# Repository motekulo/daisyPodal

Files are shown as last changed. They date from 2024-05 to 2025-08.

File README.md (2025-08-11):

# Crouds

A guitar pedal that will run patches prototyped on a Daisy Pod. I've started with making it through hole and accessible to build.

[Here's a demo](https://www.youtube.com/watch?v=Z1YsjiImZnQ) of some of the early effects and overall idea.

## Thanks

- For hardware thanks to work on the Dasiy Petal, the Terrarium and the work of  [Keith Shepherd](https://github.com/bkshepherd) 
- Timothy Schoen and other developers (Alex Mitchell, for example) for Plugdata
- Wasted Audio for the [Heavy hvcc compiler](https://wasted-audio.github.io/hvcc/)
- Graham Wakefield and Gregory Taylor for [Generating Sound and Organizing Time](https://cycling74.com/books/go)

## Things to do - v0.3 to 0.4

- J1-8 labels can go on back of board as well
- fix encoder pins (currently the wrong way around)
- fix schematic connection between pins 1 and 2 of TL074
- increase width of board, and bevel corners to fit in enclosure

## Videos

[Version 0.3 with a delay/ looper patch](https://youtu.be/q5X9XX3Vkqw)

[Version 0.3 with a distortion patch](https://youtu.be/5CY0gC0ThXo)

## Roadmap
SMD version as well as through hole.

## About me
I'm a musician/ lecturer - https://researchers.mq.edu.au/en/persons/denis-crowdy, https://codemusic.studio

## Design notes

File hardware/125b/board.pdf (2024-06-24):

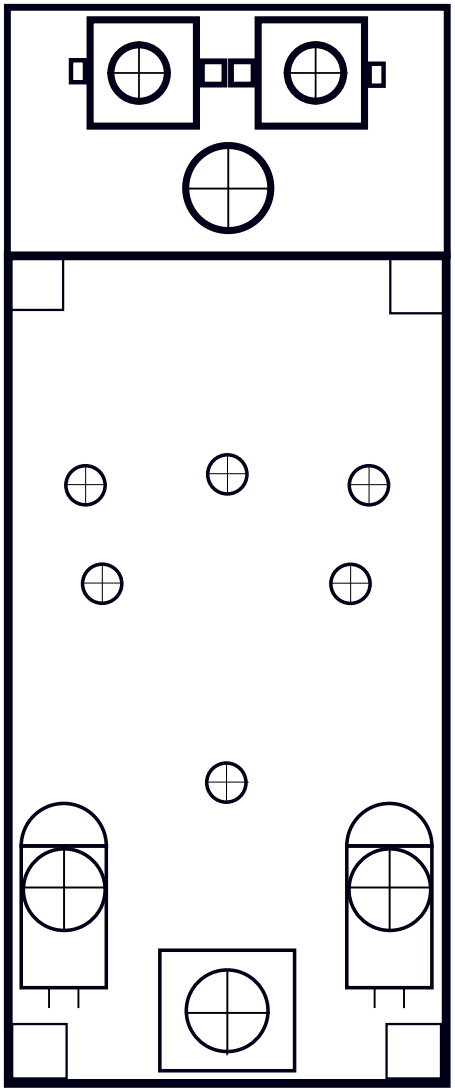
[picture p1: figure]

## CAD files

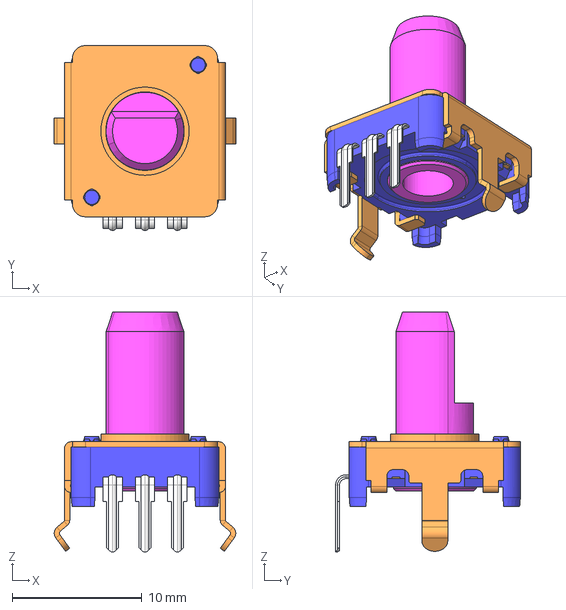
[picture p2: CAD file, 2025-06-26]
hardware/3dmodels/ec12e24204a2.stp
14.0 x 14.2 x 18.5 mm

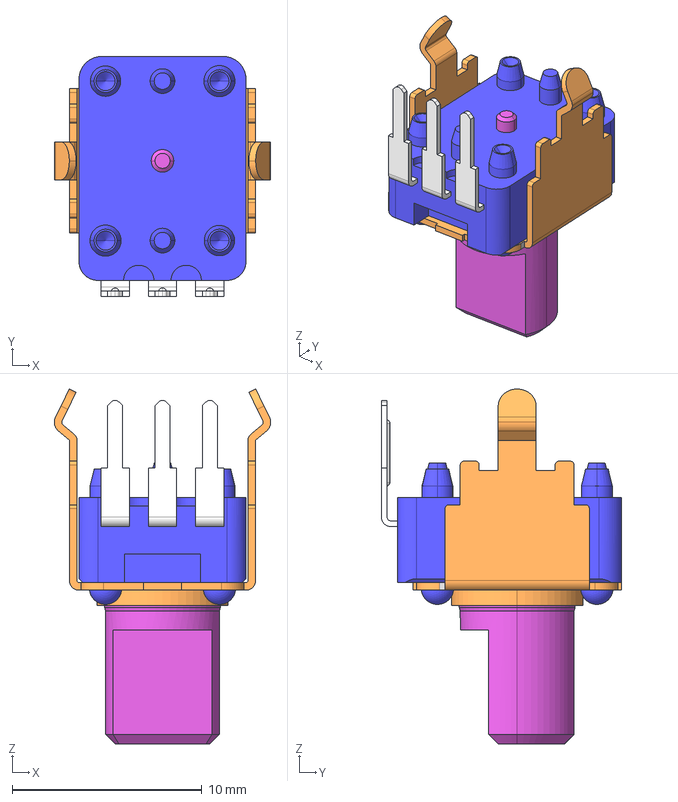
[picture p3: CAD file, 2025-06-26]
hardware/3dmodels/rk09k1130a6s.stp
11.4 x 12.7 x 18.7 mm

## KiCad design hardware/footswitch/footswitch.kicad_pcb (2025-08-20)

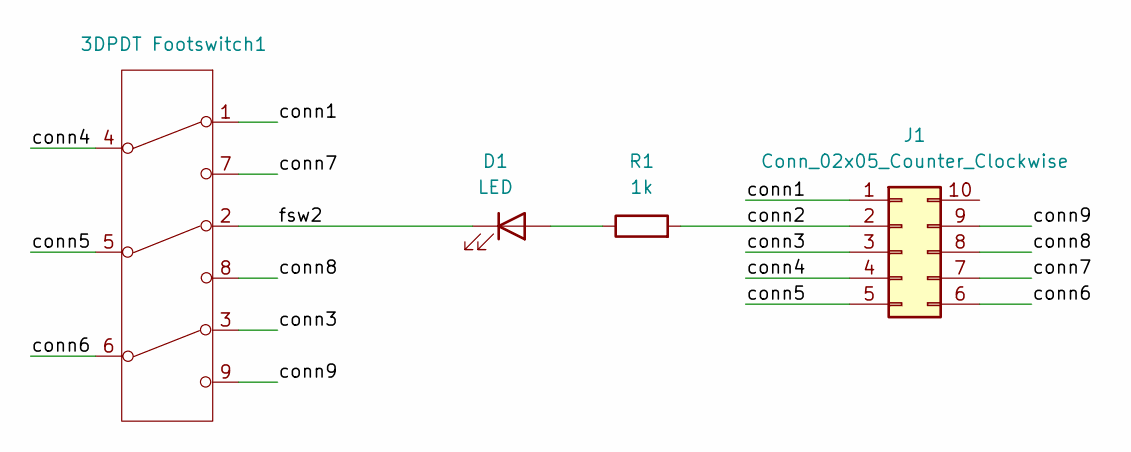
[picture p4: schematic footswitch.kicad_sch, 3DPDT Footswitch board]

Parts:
3DPDT Footswitch1: Switches_Stomp_Switch_3PDT
D1: LED; LED_D1.8mm_W3.3mm_H2.4mm
J1: Conn_02x05_Counter_Clockwise; IDC-Header_2x05_P2.54mm_Vertical
R1: 1k; R_Axial_DIN0207_L6.3mm_D2.5mm_P10.16mm_Horizontal

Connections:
/conn1: 3DPDT Footswitch1.1 (A), J1.1
/conn2: J1.2, R1.2
/conn3: 3DPDT Footswitch1.3 (C), J1.3
/conn4: 3DPDT Footswitch1.4 (D), J1.4
/conn5: 3DPDT Footswitch1.5 (E), J1.5
/conn6: 3DPDT Footswitch1.6 (F), J1.6
/conn7: 3DPDT Footswitch1.7 (G), J1.7
/conn8: 3DPDT Footswitch1.8 (G), J1.8
/conn9: 3DPDT Footswitch1.9 (G), J1.9
/fsw2: 3DPDT Footswitch1.2 (B), D1.1 (K)
unnamed: D1.2 (A), R1.1

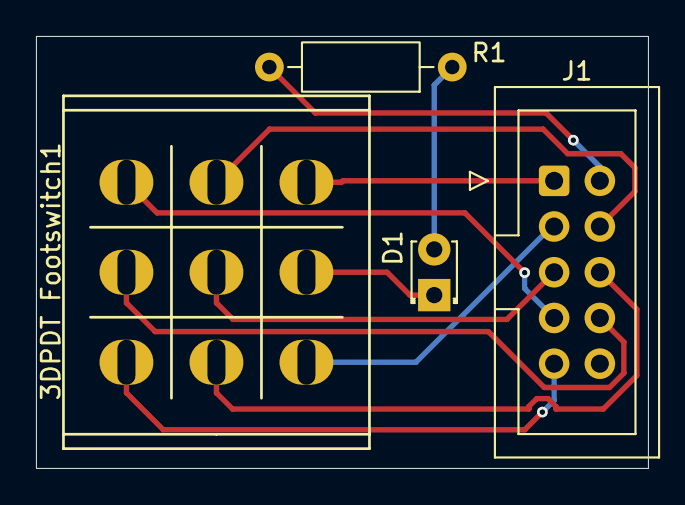
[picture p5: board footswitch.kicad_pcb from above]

Board: 2 copper layers, 34.0 x 24.0 mm, 4 parts (0 on the bottom side), 11 nets.

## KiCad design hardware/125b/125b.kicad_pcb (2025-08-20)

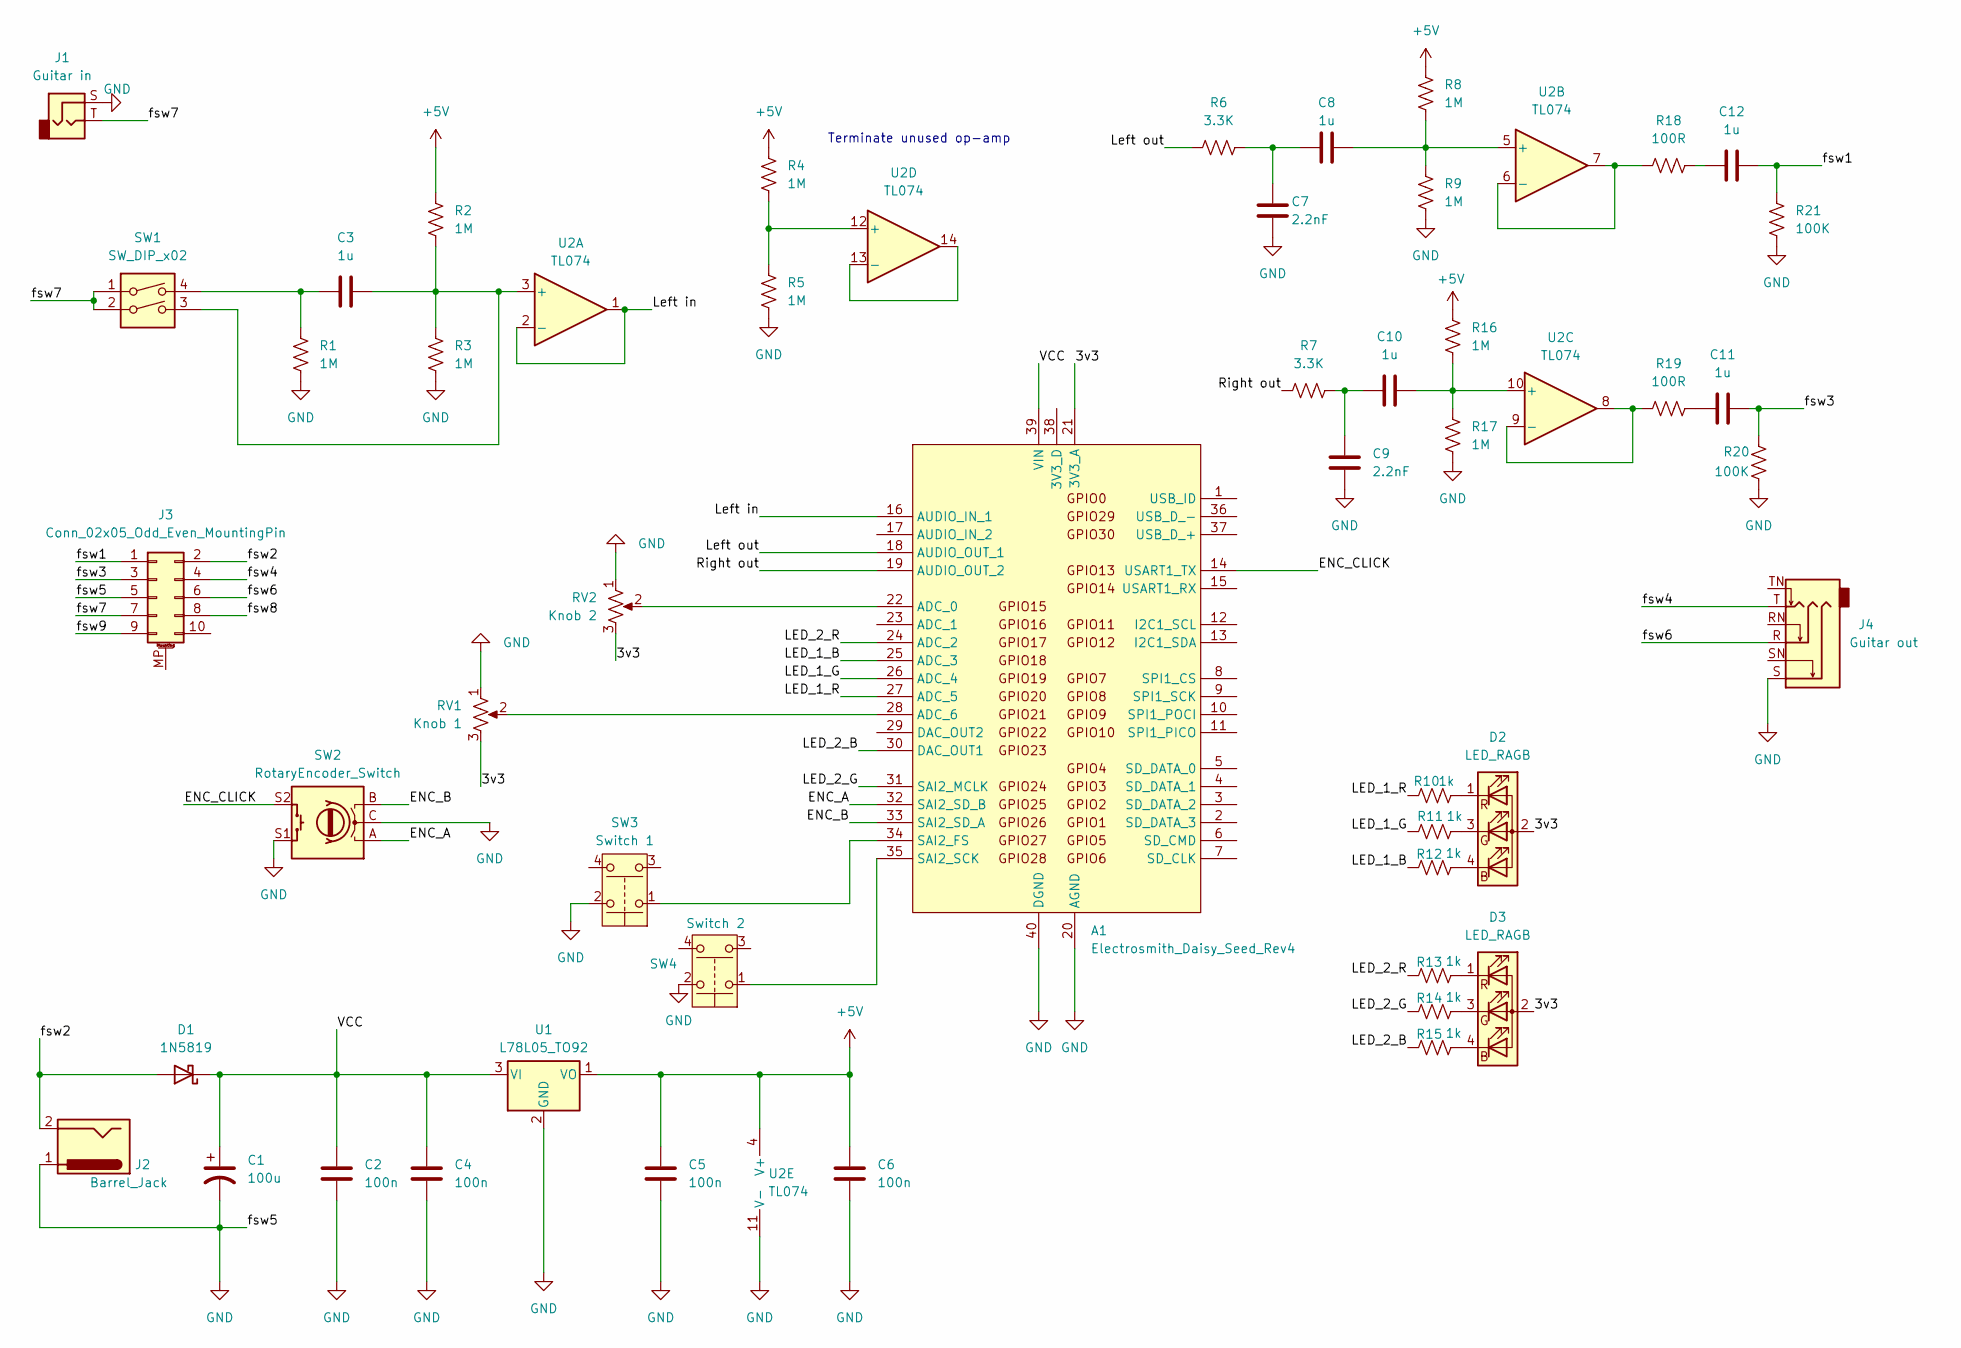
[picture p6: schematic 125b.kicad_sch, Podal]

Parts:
A1: Electrosmith_Daisy_Seed_Rev4; Electrosmith_Daisy_Seed
C1: 100u; C_Radial_D5.0mm_H11.0mm_P2.00mm
C2, C4, C5, C6: 100n; C_0805_2012Metric
C3, C8, C10, C11, C12: 1u; C_0805_2012Metric
C7, C9: 2.2nF; C_0805_2012Metric
D1: 1N5819; D_DO-41_SOD81_P7.62mm_Horizontal
D2, D3: LED_RAGB; LED_D5.0mm-4_RGB_Wide_Pins
J1: Guitar in; Jack_6.35mm_Neutrik_NRJ6HF-1-AU_Horizontal
J2: Barrel_Jack; BarrelJack_Horizontal
J3: Conn_02x05_Odd_Even_MountingPin; IDC-Header_2x05_P2.54mm_Vertical
J4: Guitar out; Jack_6.35mm_Neutrik_NRJ6HF-1-AU_Horizontal
R1, R2, R3, R4, R5, R8, R9, R16, R17: 1M; R_0805_2012Metric
R6, R7: 3.3K; R_0805_2012Metric
R10, R11, R12, R13, R14, R15: 1k; R_0805_2012Metric
R18, R19: 100R; R_0805_2012Metric
R20, R21: 100K; R_0805_2012Metric
RV1: Knob 1; Potentiometer_Alps_RK09K_Single_Vertical
RV2: Knob 2; Potentiometer_Alps_RK09K_Single_Vertical
SW1: SW_DIP_x02; SW_DIP_SPSTx02_Slide_9.78x7.26mm_W7.62mm_P2.54mm
SW2: RotaryEncoder_Switch; RotaryEncoder_Alps_EC12E-Switch_Vertical_H20mm
SW3: Switch 1; SolderWire-0.5sqmm_1x02_P4.6mm_D0.9mm_OD2.1mm
SW4: Switch 2; SolderWire-0.5sqmm_1x02_P4.6mm_D0.9mm_OD2.1mm
U1: L78L05_TO92; TO-92_Inline_Wide_78L05_dc
U2: TL074; SOIC-14_3.9x8.7mm_P1.27mm

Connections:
+5V: C5.2, C6.2, R2.1, R4.1, R8.1, R16.1, U1.1 (VO), U2.4 (V+)
/3v3: A1.21 (3V3_A), D2.2 (A), D3.2 (A), RV1.3, RV2.3
/ENC_A: A1.32 (SAI2_SD_B), SW2.A
/ENC_B: A1.33 (SAI2_SD_A), SW2.B
/ENC_CLICK: A1.14 (USART1_TX), SW2.S2
/LED_1_B: A1.25 (ADC_3), R12.1
/LED_1_G: A1.26 (ADC_4), R11.1
/LED_1_R: A1.27 (ADC_5), R10.1
/LED_2_B: A1.30 (DAC_OUT1), R15.1
/LED_2_G: A1.31 (SAI2_MCLK), R14.1
/LED_2_R: A1.24 (ADC_2), R13.1
/Left in: A1.16 (AUDIO_IN_1), U2.1, U2.2 (-)
/Left out: A1.18 (AUDIO_OUT_1), R6.1
/Right out: A1.19 (AUDIO_OUT_2), R7.1
/VCC: A1.39 (VIN), C1.1, C2.2, C4.2, D1.1 (K), U1.3 (VI)
/fsw1: C12.2, J3.1, R21.1
/fsw2: D1.2 (A), J2.2, J3.2
/fsw3: C11.2, J3.3, R20.1
/fsw4: J3.4, J4.T
/fsw6: J3.6, J4.R
/fsw7: J1.T, J3.7, SW1.1, SW1.2
/fsw8: J3.8
/fsw9: J3.9
GND: A1.20 (AGND), A1.40 (DGND), C1.2, C2.1, C4.1, C5.1, C6.1, C7.1, C9.1, J1.S, J2.1, J3.5, J4.S, R1.2, R3.2, R5.2, R9.2, R17.2, R20.2, R21.2, RV1.1, RV2.1, SW2.C, SW2.S1, SW3.2, SW4.2, U1.2 (GND), U2.11 (V-)
unnamed: A1.22 (ADC_0), RV2.2
unnamed: A1.28 (ADC_6), RV1.2
unnamed: A1.34 (SAI2_FS), SW3.1
unnamed: A1.35 (SAI2_SCK), SW4.1
unnamed: C3.1, R1.1, SW1.4
unnamed: C7.2, C8.1, R6.2
unnamed: C9.2, C10.1, R7.2
unnamed: C11.1, R19.2
unnamed: C12.1, R18.2
unnamed: D2.4 (BK), R12.2
unnamed: D2.3 (GK), R11.2
unnamed: D2.1 (RK), R10.2
unnamed: D3.4 (BK), R15.2
unnamed: D3.3 (GK), R14.2
unnamed: D3.1 (RK), R13.2
unnamed: C3.2, R2.2, R3.1, SW1.3, U2.3 (+)
unnamed: C8.2, R8.2, R9.1, U2.5 (+)
unnamed: R18.1, U2.6 (-), U2.7
unnamed: C10.2, R16.2, R17.1, U2.10 (+)
unnamed: R19.1, U2.8, U2.9 (-)
unnamed: R4.2, R5.1, U2.12 (+)
unnamed: U2.13 (-), U2.14

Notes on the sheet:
Terminate unused op-amp

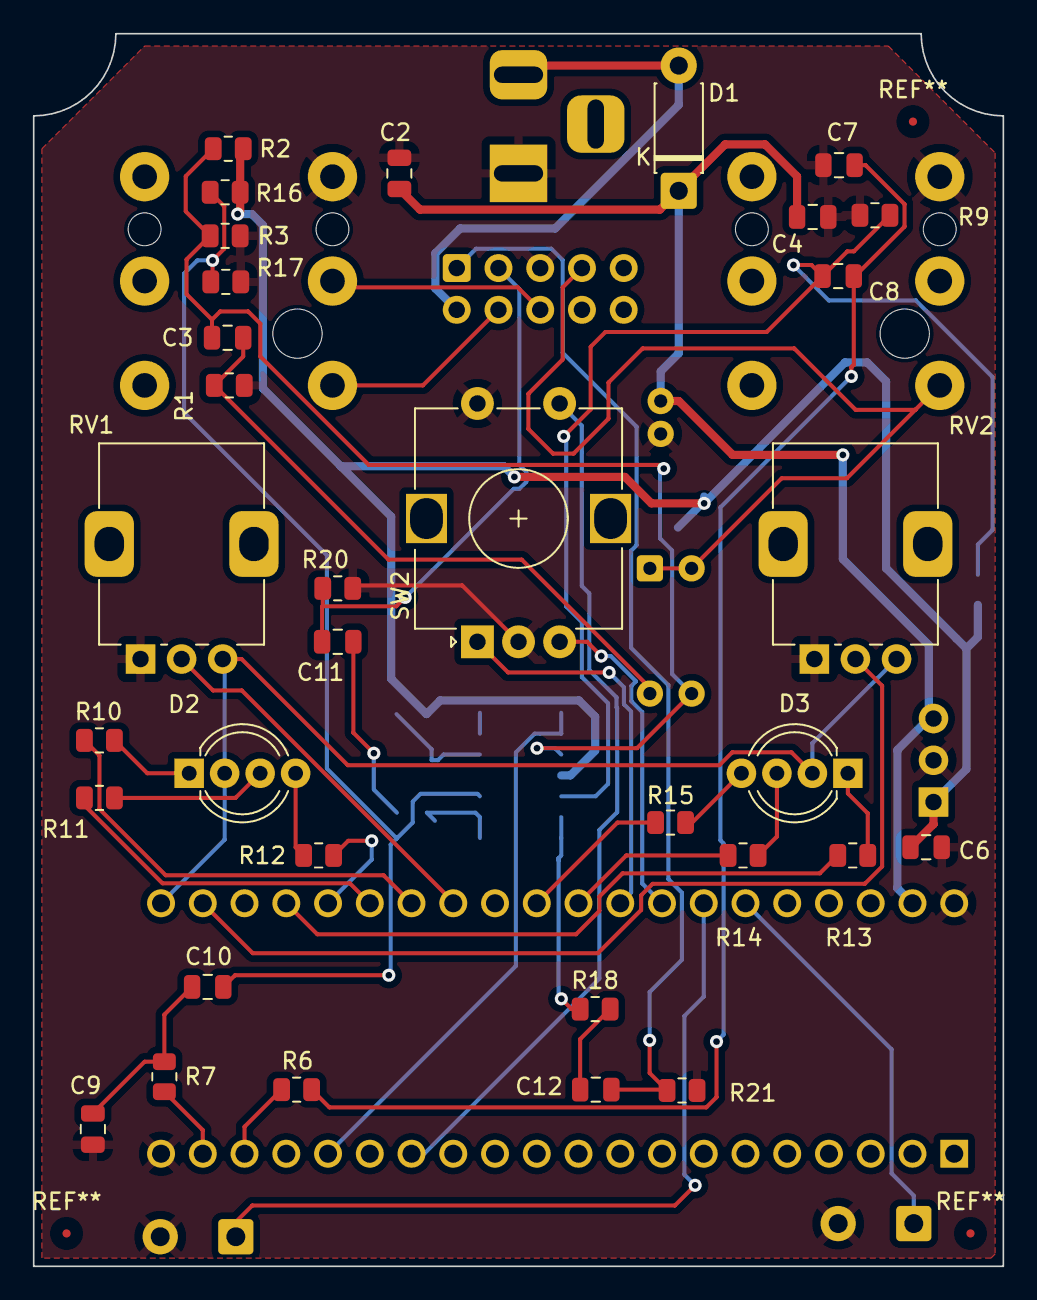
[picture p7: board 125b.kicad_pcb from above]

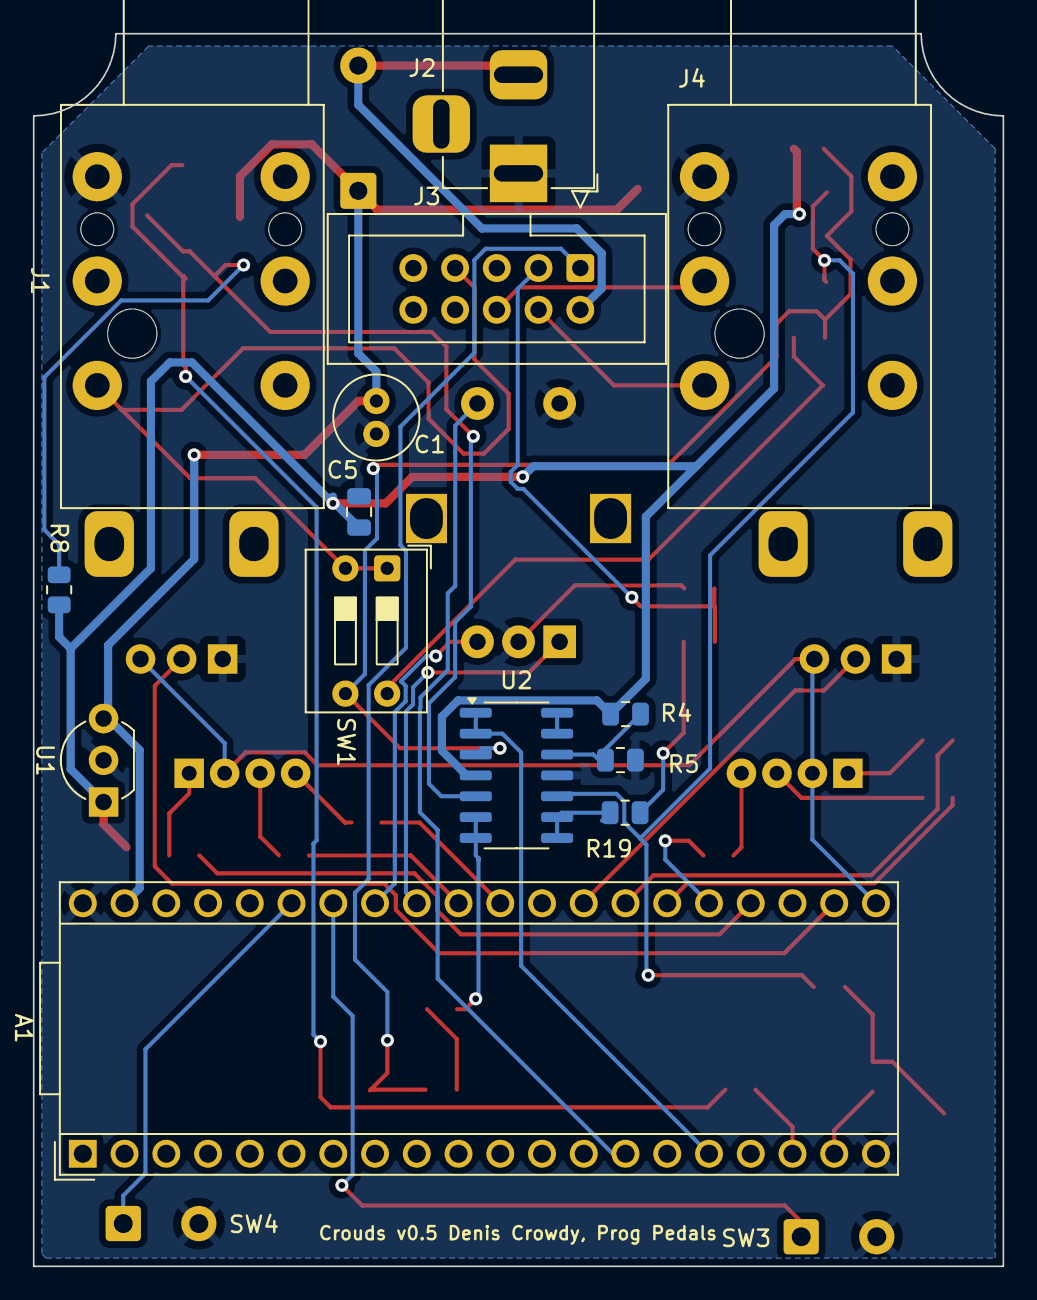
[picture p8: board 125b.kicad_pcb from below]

Board: 2 copper layers, 59.0 x 75.0 mm, 49 parts (16 on the bottom side), 44 nets.

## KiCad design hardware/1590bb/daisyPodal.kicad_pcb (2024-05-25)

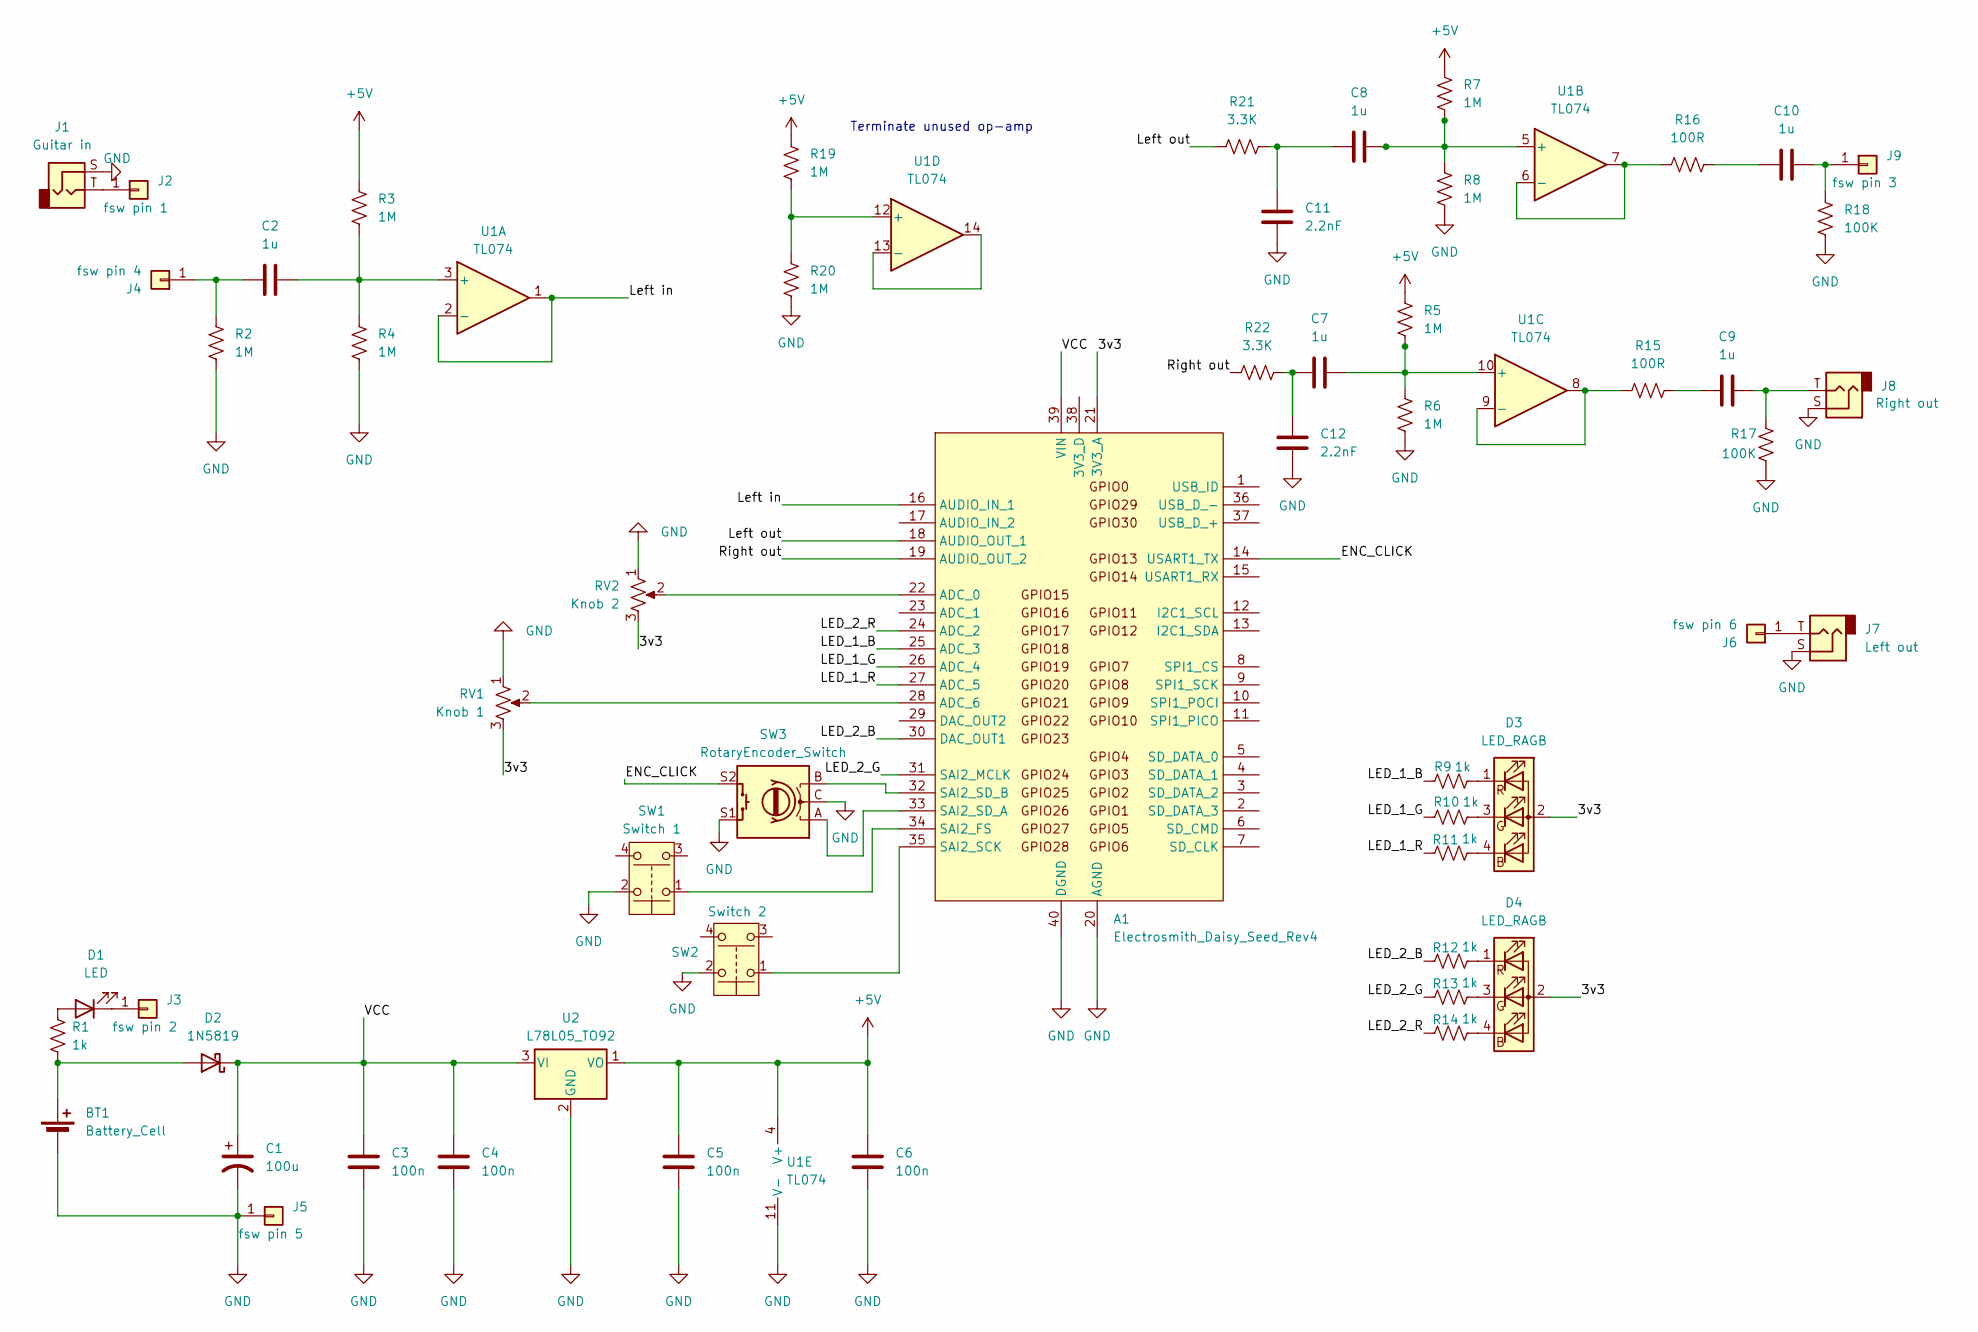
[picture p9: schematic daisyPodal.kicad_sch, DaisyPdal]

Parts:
A1: Electrosmith_Daisy_Seed_Rev4; Electrosmith_Daisy_Seed
BT1: Battery_Cell; BarrelJack_Horizontal_centre_negative
C1: 100u; C_Radial_D10.0mm_H16.0mm_P5.00mm
C2, C7, C8, C9, C10: 1u; C_Rect_L7.0mm_W2.5mm_P5.00mm
C3, C4, C5, C6: 100n; C_Rect_L7.0mm_W2.5mm_P5.00mm
C11, C12: 2.2nF; C_Rect_L7.0mm_W2.5mm_P5.00mm
D1: LED; LED_D1.8mm_W3.3mm_H2.4mm
D2: 1N5819; D_DO-41_SOD81_P7.62mm_Horizontal
D3, D4: LED_RAGB; LED_D5.0mm-4_RGB
J1: Guitar in; Jack_6.35mm_Neutrik_NRJ6HM-1_Horizontal
J2: fsw pin 1; SolderWire-0.75sqmm_1x01_D1.25mm_OD3.5mm
J3: fsw pin 2; SolderWire-0.75sqmm_1x01_D1.25mm_OD3.5mm
J4: fsw pin 4; SolderWire-0.75sqmm_1x01_D1.25mm_OD3.5mm
J5: fsw pin 5; SolderWire-0.75sqmm_1x01_D1.25mm_OD3.5mm
J6: fsw pin 6; SolderWire-0.75sqmm_1x01_D1.25mm_OD3.5mm
J7: Left out; Jack_6.35mm_Neutrik_NRJ6HM-1_Horizontal
J8: Right out; Jack_6.35mm_Neutrik_NRJ6HM-1_Horizontal
J9: fsw pin 3; SolderWire-0.75sqmm_1x01_D1.25mm_OD3.5mm
R1, R9, R10, R11, R12, R13, R14: 1k; R_Axial_DIN0207_L6.3mm_D2.5mm_P10.16mm_Horizontal
R2, R3, R4, R5, R6, R7, R8, R19, R20: 1M; R_Axial_DIN0207_L6.3mm_D2.5mm_P10.16mm_Horizontal
R15, R16: 100R; R_Axial_DIN0207_L6.3mm_D2.5mm_P10.16mm_Horizontal
R17, R18: 100K; R_Axial_DIN0207_L6.3mm_D2.5mm_P10.16mm_Horizontal
R21, R22: 3.3K; R_Axial_DIN0207_L6.3mm_D2.5mm_P10.16mm_Horizontal
RV1: Knob 1; Potentiometer_Alps_RK09K_Single_Vertical
RV2: Knob 2; Potentiometer_Alps_RK09K_Single_Vertical
SW1: Switch 1; SolderWire-0.75sqmm_1x02_P7mm_D1.25mm_OD3.5mm
SW2: Switch 2; SolderWire-0.75sqmm_1x02_P7mm_D1.25mm_OD3.5mm
SW3: RotaryEncoder_Switch; RotaryEncoder_Alps_EC12E-Switch_Vertical_H20mm
U1: TL074
U2: L78L05_TO92; TO-92_Inline_Wide_78L05_dc

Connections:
+5V: C5.2, C6.2, R3.1, R5.1, R7.1, R19.1, U1.4 (V+), U2.1 (VO)
/3v3: A1.21 (3V3_A), D3.2 (A), D4.2 (A), RV1.3, RV2.3
/ENC_CLICK: A1.14 (USART1_TX), SW3.S2
/LED_1_B: A1.25 (ADC_3), R9.1
/LED_1_G: A1.26 (ADC_4), R10.1
/LED_1_R: A1.27 (ADC_5), R11.1
/LED_2_B: A1.30 (DAC_OUT1), R12.1
/LED_2_G: A1.31 (SAI2_MCLK), R13.1
/LED_2_R: A1.24 (ADC_2), R14.1
/Left in: A1.16 (AUDIO_IN_1), U1.1, U1.2 (-)
/Left out: A1.18 (AUDIO_OUT_1), R21.1
/Right out: A1.19 (AUDIO_OUT_2), R22.1
/VCC: A1.39 (VIN), C1.1, C3.2, C4.2, D2.1 (K), U2.3 (VI)
GND: A1.20 (AGND), A1.40 (DGND), BT1.2 (-), C1.2, C3.1, C4.1, C5.1, C6.1, C11.1, C12.1, J1.S, J5.1, J7.S, J8.S, R2.2, R4.2, R6.2, R8.2, R17.2, R18.2, R20.2, RV1.1, RV2.1, SW1.2, SW2.2, SW3.C, SW3.S1, U1.11 (V-), U2.2 (GND)
unnamed: A1.22 (ADC_0), RV2.2
unnamed: A1.28 (ADC_6), RV1.2
unnamed: A1.34 (SAI2_FS), SW1.1
unnamed: A1.35 (SAI2_SCK), SW2.1
unnamed: A1.33 (SAI2_SD_A), SW3.A
unnamed: A1.32 (SAI2_SD_B), SW3.B
unnamed: BT1.1 (+), D2.2 (A), R1.1
unnamed: C9.1, R15.2
unnamed: C9.2, J8.T, R17.1
unnamed: C10.1, R16.2
unnamed: C8.1, C11.2, R21.2
unnamed: C7.1, C12.2, R22.2
unnamed: D1.2 (A), R1.2
unnamed: D1.1 (K), J3.1
unnamed: D3.4 (BK), R11.2
unnamed: D3.3 (GK), R10.2
unnamed: D3.1 (RK), R9.2
unnamed: D4.4 (BK), R14.2
unnamed: D4.3 (GK), R13.2
unnamed: D4.1 (RK), R12.2
unnamed: J1.T, J2.1
unnamed: C2.1, J4.1, R2.1
unnamed: J6.1, J7.T
unnamed: C10.2, J9.1, R18.1
unnamed: C2.2, R3.2, R4.1, U1.3 (+)
unnamed: C8.2, R7.2, R8.1, U1.5 (+)
unnamed: R16.1, U1.6 (-), U1.7
unnamed: C7.2, R5.2, R6.1, U1.10 (+)
unnamed: R15.1, U1.8, U1.9 (-)
unnamed: R19.2, R20.1, U1.12 (+)
unnamed: U1.13 (-), U1.14

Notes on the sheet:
Terminate unused op-amp

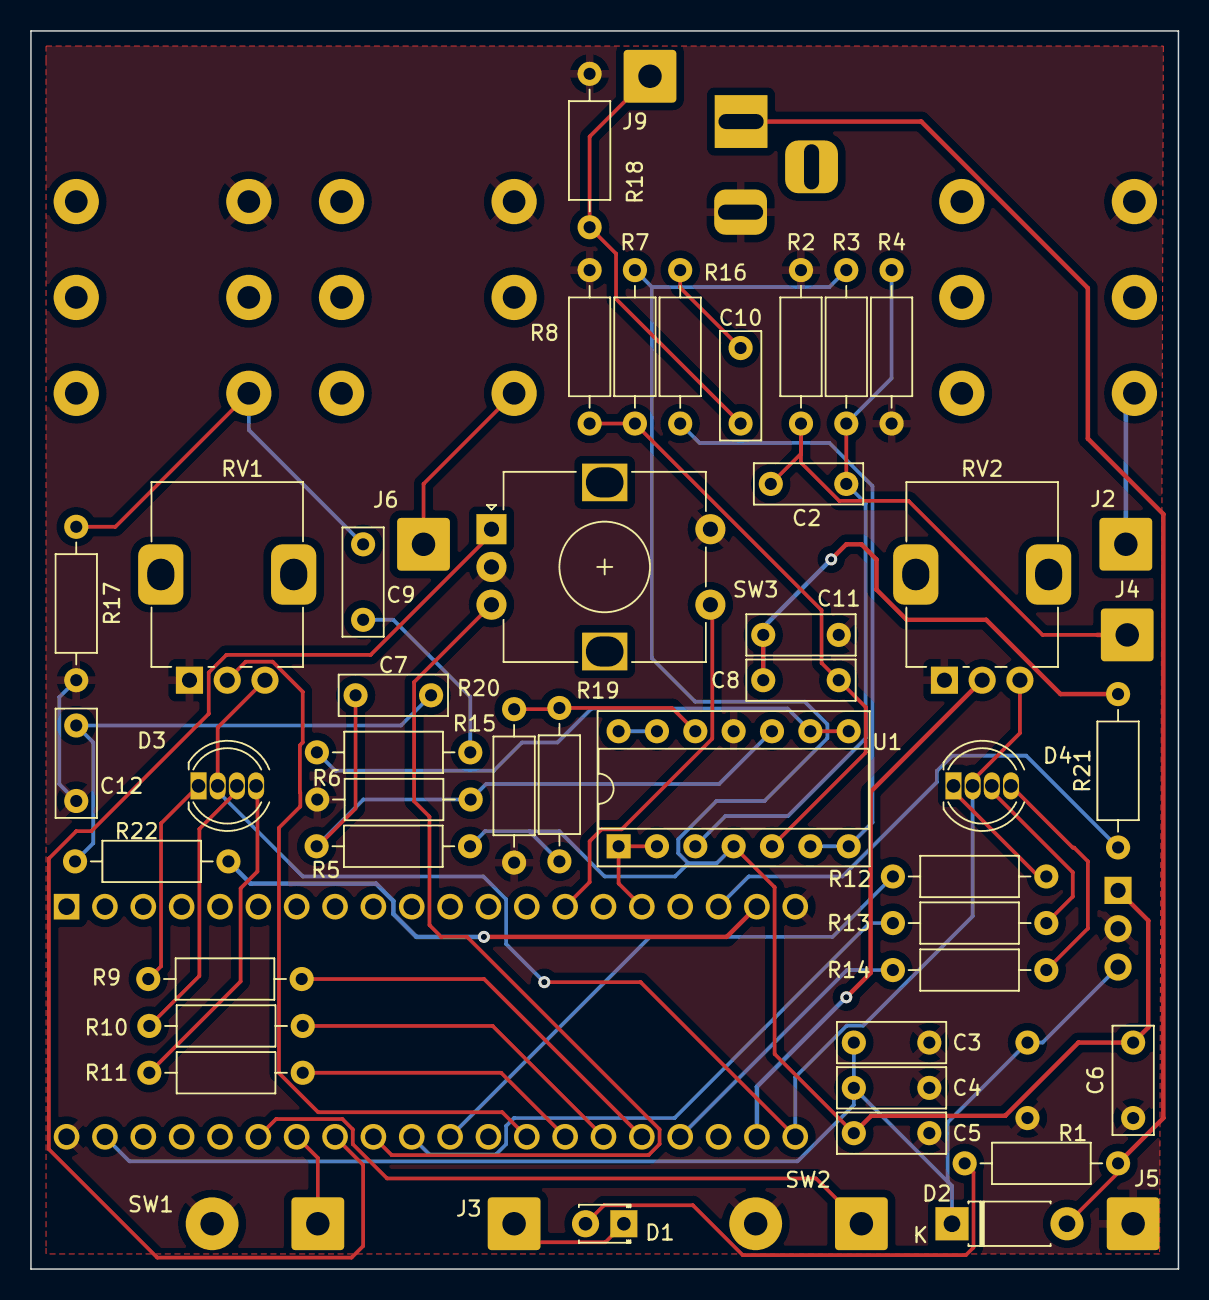
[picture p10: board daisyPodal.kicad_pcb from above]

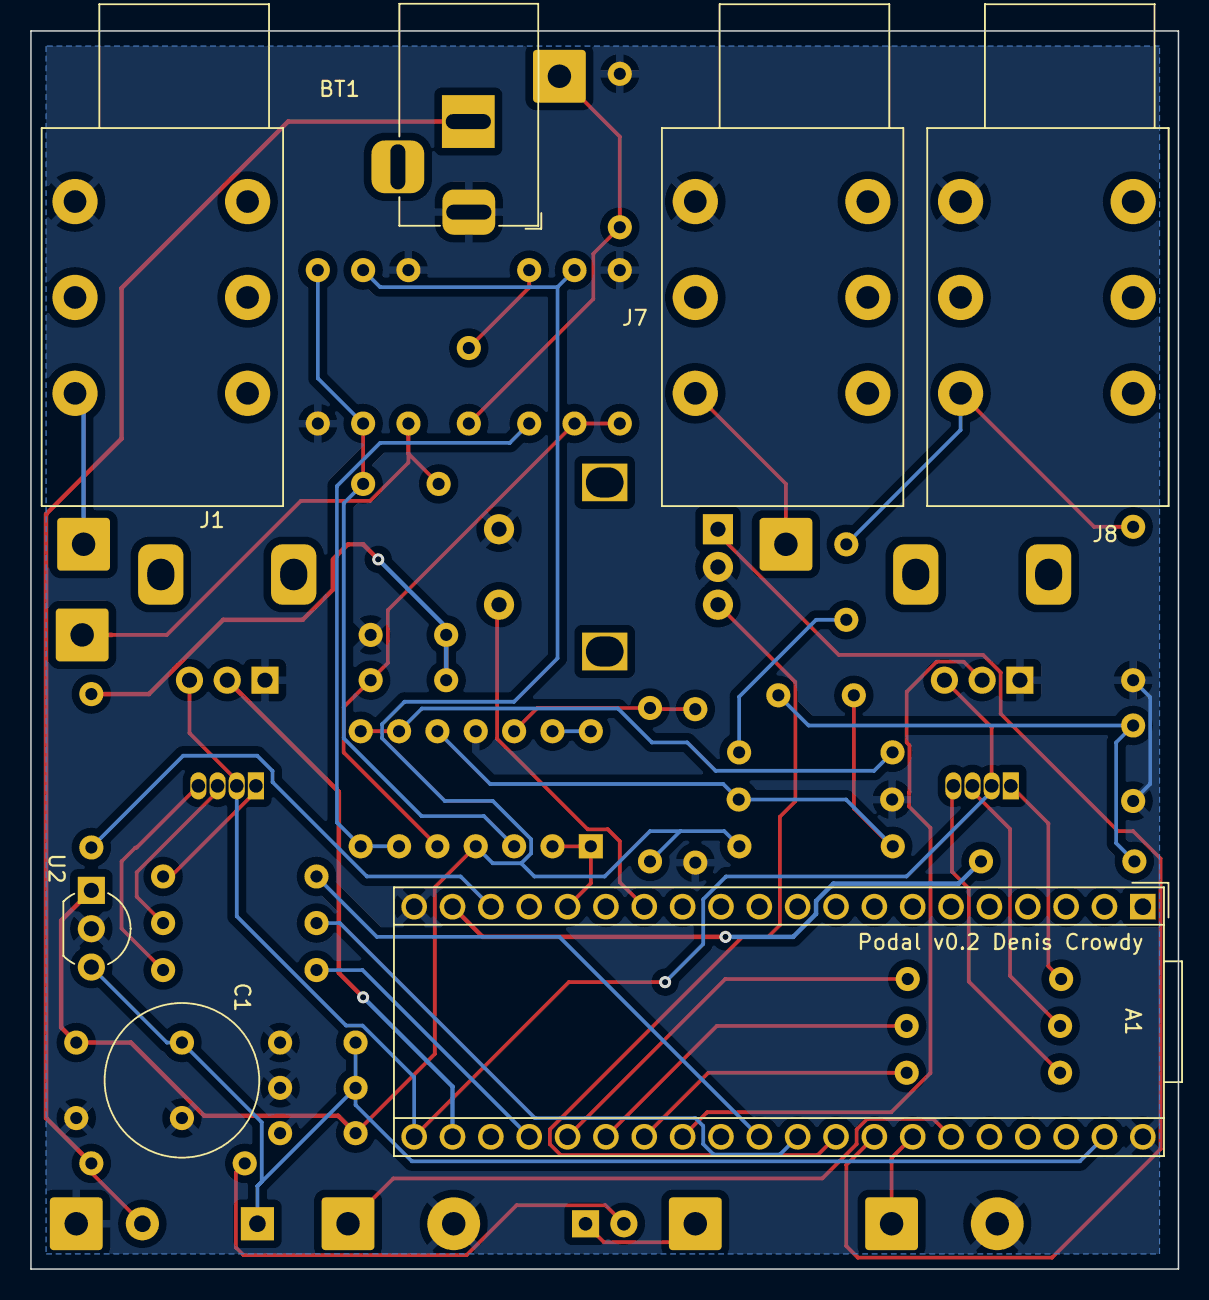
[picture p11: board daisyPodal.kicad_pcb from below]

Board: 2 copper layers, 76.0 x 82.0 mm, 56 parts (7 on the bottom side), 45 nets.

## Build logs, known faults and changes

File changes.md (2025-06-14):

# Changes

## 0.2
- Fix barreljack footprint for centre -ve
- Bigger holes for LM7805 - power regulator
- Spacing on box caps (too wide currently); check with ones from diypedals
- Move C2 to back of board
- LM7805 to back of the board
- J1-8 labels can go on back of board as well
- Daisy could go on the back of the board - have to press buttons to flash it.
- Should solder in sockets so that the Seed can be inserted without soldering it in place permanently
- Holes for push button switches need to be larger
- add resistors and check circuit for RGB LEDs
- pots are the wrong way around
- Add stereo output

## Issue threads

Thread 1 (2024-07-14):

encoder output inverted in 1590b (0.3) circuit

motekulo, 2024-07-14:
Turning to the right generates -1, and to the left +1. Patches need a workaround until this is fixed in 0.4

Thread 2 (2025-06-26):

Pads for switch connections are too small

motekulo, 2025-06-26:
Use larger pads for sw1 and sw2

motekulo, 2025-06-26:
Might be redundant, if moving to SMD for 0.5?

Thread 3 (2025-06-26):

Footprints of large (1uF) caps are too small

motekulo, 2025-06-26:
They'll fit at the moment, but it gets tight around the TL074

motekulo, 2025-06-26:
Might be redundant, if moving to SMD for 0.5?

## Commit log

2024-02-11 Start the schematic
    [daisyPdal.kicad_pcb, daisyPdal.kicad_sch]
2024-02-25 Get the input and output buffers on the schematic
    [daisyPdal.kicad_pcb, daisyPdal.kicad_sch]
2024-03-05 Update schematic with pots, switches, encoder, LEDs
    [daisyPdal.kicad_pcb, daisyPdal.kicad_sch]
2024-03-30 Lots of work on the schematic and PCB
    [daisyPdal.kicad_pcb, daisyPdal.kicad_sch]
2024-03-31 Move pots further apart; separate close traces
    [daisyPdal.kicad_pcb]
2024-03-31 Replace u1 footprint to get correct spacing
    [daisyPdal.kicad_pcb, daisyPdal.kicad_sch]
2024-04-09 Rename - Podal
    [daisyPodal.kicad_pcb, daisyPodal.kicad_sch]
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2024-04-23 Add simple delay patch
    [daisyPodal.kicad_pcb]
2024-04-23 Sort out correct RGB LEDS - RAGB
    Common anode on the Pod
    [daisyPodal.kicad_pcb, daisyPodal.kicad_sch]
2024-04-23 With resistors for the RGB LEDs
    [daisyPodal.kicad_sch]
2024-04-23 Get the pots the right way around
    [daisyPodal.kicad_sch]
2024-04-25 Increase hole size of pads for LM7805
    [daisyPodal.kicad_pcb]
2024-04-25 Flip LM7805 to back of board
    [daisyPodal.kicad_pcb]
2024-04-25 Add right out - stereo now
    Replaced TL072 with TL074
    [daisyPodal.kicad_pcb, daisyPodal.kicad_sch]
2024-04-25 reduce size of box capacitors to fit caps we use
    [daisyPodal.kicad_pcb, daisyPodal.kicad_sch]
2024-04-25 Place components on PCB in sensible blocks
    [daisyPodal.kicad_pcb, daisyPodal.kicad_sch]
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2024-04-27 Connect everything together on PCB
    [daisyPodal.kicad_pcb]
2024-04-28 Fix input buffer circuit and re-jig PCB
    [daisyPodal.kicad_pcb, daisyPodal.kicad_sch]
2024-04-30 Terminate unused op-amp
    [daisyPodal.kicad_pcb, daisyPodal.kicad_sch]
2024-04-30 Add low pass filters at 22kHz on outputs
    Following advice from Daisy forum discussion on Seed rev 7 noise.
    Possible to jumper over these if not desired.
    [daisyPodal.kicad_pcb, daisyPodal.kicad_sch]
2024-04-30 Tidy up various overlaps
    [daisyPodal.kicad_pcb]
2024-05-01 Tidy labels, print gerbers - mark as v0.2
    [daisyPodal.kicad_pcb]
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2024-05-11 Fix missing connection in schematic on input stage
    Means a jumper needed between pins 1 and 2 of TL074
    on board v0.2
    [daisyPodal.kicad_pcb, daisyPodal.kicad_sch]
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2024-05-14 Trying to get a switch to subdivide the beat
    Not working
2024-05-14 Tidy up repository
    [daisyPodal.kicad_pcb, daisyPodal.kicad_sch]
2024-05-20 Copy files and restart pcb for a 1590b version
    [podal_1590b.kicad_pcb, podal_1590b.kicad_sch]
2024-05-22 Compressor working with sensible led output
    [podal_1590b.kicad_pcb, podal_1590b.kicad_sch]
2024-05-25 Start work on connecting traces
    [podal_1590b.kicad_pcb]
2024-05-25 See if we can get some icad compatibility between mac and linux
    [podal_1590b.kicad_pcb]
2024-05-25 Connect everything together
    Board seems messy but good experiment with so many vias?
    [podal_1590b.kicad_pcb]
2024-05-25 Reorganise hardware into enclosure size
    [daisyPodal.kicad_pcb, daisyPodal.kicad_sch, podal_1590b.kicad_pcb]
2024-05-26 Tidy up pcb and compressor
    [podal_1590b.kicad_pcb]
2024-05-26 Add footprint for the LM7805
    [podal_1590b.kicad_pcb, podal_1590b.kicad_sch]
2024-05-26 Fix Red and blue LEDs - were the wrong way round
    [podal_1590b.kicad_pcb, podal_1590b.kicad_sch]
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2025-06-01 Copy 1590b version across to start on 125b version
    Heading towards 0.4
    [125b-B_Cu.gbr, 125b-B_Mask.gbr, 125b-B_Paste.gbr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]
2025-06-07 Add switch for line input toggle and fix stereo out
    Bypass will be different for stereo out
    [125b.kicad_sch]
2025-06-08 Tidy up scehmatic - grid snapping
    [125b.kicad_sch]
2025-06-08 Update PCB and resize for 125b
    [125b.kicad_pcb, 125b.kicad_sch]
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2025-06-09 Footprints for audio and power sockets added
    Also DIP switch for line/ guitar input. Ready to start
    moving components around.
    [125b.kicad_pcb, 125b.kicad_sch]
2025-06-09 Swap encoder pins
    [125b.kicad_pcb, 125b.kicad_sch]
2025-06-09 Components replaced on board after rejig
    Back with the audio and power sockets on board
    [125b.kicad_pcb, 125b.kicad_sch]
2025-06-12 Fix unconnected items and update footprints
    [125b.kicad_pcb]
2025-06-12 Cut out corners for 125b enclosure
    [125b.kicad_pcb]
2025-06-12 Flip wire connectors to back of board
    Various adjustments of labels and fix overlapping footprints
    [125b.kicad_pcb]
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2025-06-13 Final minor tweaks then export as 0.4
    Off to fabrication
    [125b-B_Cu.gbr, 125b-B_Mask.gbr, 125b-B_Paste.gbr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]
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2025-06-20 Update a drill template for the 125b build v 0.4
    [125b.kicad_pcb]
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2025-06-26 Add 3d models of Daisy, pots, encoder and audio socket
    [125b.kicad_pcb, ec12e24204a2.stp, rk09k1130a6s.stp]
2025-07-10 add a 3DPDT footswitch to kicad and then schematic
    [125b.kicad_sch]
2025-07-14 Add schematic and pcb files for footswitch board
    [125b.kicad_sch, footswitch.kicad_sch]
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2025-07-14 New project for the footswitch board
    [125b.kicad_sch, footswitch.kicad_pcb, footswitch.kicad_sch]
2025-07-14 Connect up footswitch to IDC 2 x 5
    [footswitch.kicad_pcb, footswitch.kicad_sch]
2025-07-14 Wider traces for footswitch PCB and connect main board
    [125b.kicad_sch, footswitch.kicad_pcb, footswitch.kicad_sch]
2025-07-30 Start work on SMD caps and resistors
    [125b.kicad_pcb, 125b.kicad_sch]
2025-07-30 Increase size of holes for switch connectors
    [125b.kicad_pcb, 125b.kicad_sch]
2025-07-31 Update 3d models and adjust footprints for local project lib
    [125b.kicad_pcb, 125b.kicad_sch]
2025-08-01 Tidy up position of SMD components
    [125b.kicad_pcb]
2025-08-02 Increase RGB LED footprint for easier soldering
    Also re-adjustLEDs, pots and encoder for symmetry
    [125b.kicad_pcb, 125b.kicad_sch]
2025-08-03 Try pin sockets for the footswitch connector
    Can just solder some ribbon wire for this version
    [125b.kicad_pcb, 125b.kicad_sch]
2025-08-03 Add GND plane zones
    [125b.kicad_pcb]
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2025-08-13 Set up power nets to have wider traces
    [125b.kicad_pcb, 125b.kicad_sch]
2025-08-13 Add bypass LED and resistor to footswitch board
    [footswitch.kicad_sch]
2025-08-14 Resize footswitch board, adjust footprints
    Resistor and diode added
    [footswitch.kicad_pcb, footswitch.kicad_sch]
2025-08-14 Connect everything with traces
    Corrected schematic with fsw2
    [footswitch.kicad_pcb, footswitch.kicad_sch]
2025-08-14 All components connected with new IDC socket pos
    [125b.kicad_pcb, 125b.kicad_sch]
2025-08-14 Move r8 from underneath audio socket
    [125b.kicad_pcb]
2025-08-14 Rotate IDC socket for cleaner ribbon direction
    [125b.kicad_pcb]
2025-08-14 Minor adjustments to footswitch pcb
    [footswitch.kicad_pcb]
2025-08-14 Adjust switch connector positions and add fiducials
    [125b.kicad_pcb, footswitch.kicad_pcb]
